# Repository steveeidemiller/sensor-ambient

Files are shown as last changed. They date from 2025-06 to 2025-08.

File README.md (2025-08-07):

# Sensor: Ambient
This ESP32-S3 project is designed to monitor ambient temperature, humidity, barometric pressure, air quality, sound and light levels in areas such as attics, basements, garages, etc. It provides a rich data set that can be integrated into various home automation platforms through MQTT. It also offers a detailed web interface showing current sensor status and graphs of historical data. A telemetry endpoint is also available for use with observability platforms such as Prometheus.

## Features
- Code is designed to be used with the Arduino IDE
- BME680 environmental monitoring for temperature, humidity, atmospheric pressure and air quality
- SPH0645 I2S sound sensor for ambient sound level detection. The sensor does not record audio, it measures sound levels over time.
- VEML7700 I2C light sensor for ambient light level detection. The sensor is not a camera, it uses a single pixel to measure light levels over time.
- MQTT integration with TLS, user/pass and client certificate options
- NTP support for accurate system time which is also reported to MQTT for sensor online/offline detection
- HTTP status page with detailed sensor information, environmentals, system uptime tracking and historical charts
- HTTP metrics endpoint for use with telemetry systems such as Prometheus
- TFT display support that shows current data, sensor uptime and network address information
- AC power on/off sensing to detect power outages at the sensor location
- LiPo battery backup support to power the sensor through moderate power outages

## Screenshots

### Web Interface
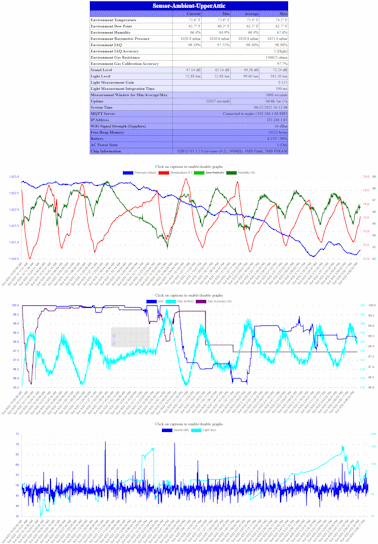
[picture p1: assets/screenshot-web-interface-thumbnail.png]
Web Interface


### MQTT
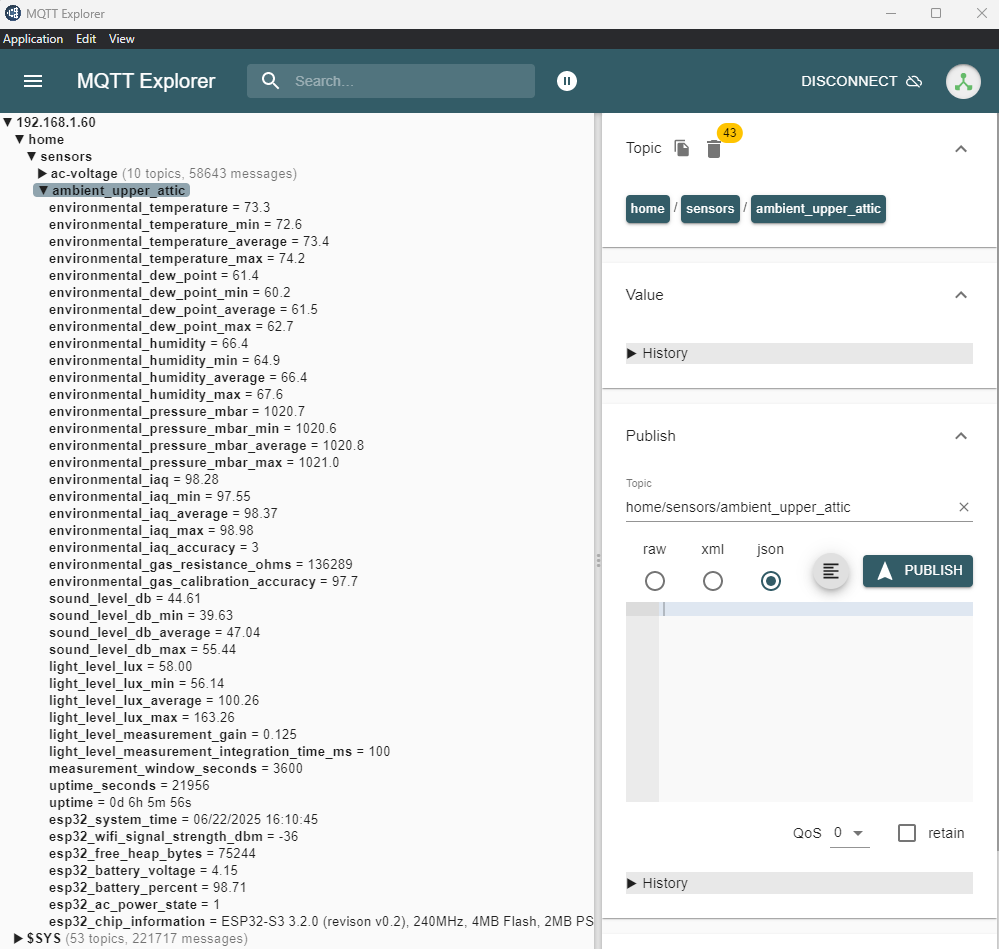
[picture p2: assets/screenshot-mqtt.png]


### Telemetry
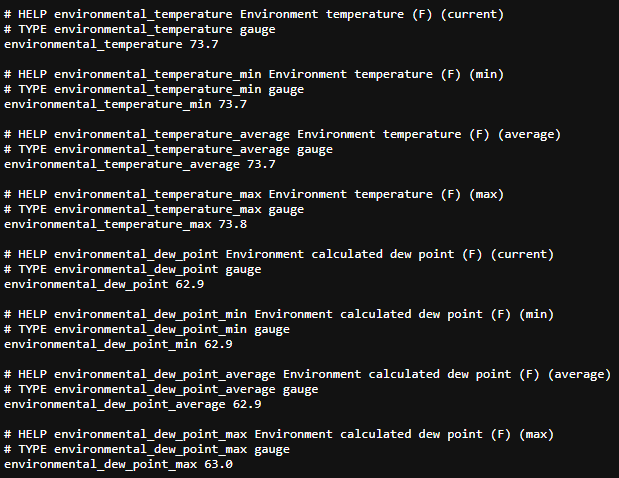
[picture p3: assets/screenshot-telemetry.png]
<br/>
NOTE: This is only a sample of the complete telemetry available.

## Bill of Materials
This solution is based on the ESP32-S3 Reverse TFT Feather from Adafruit. The device integrates a TFT display, a LiPo battery power and charging cicuit, and Qwiic-compatible Stemma QT connectors.
- ESP32-S3 Reverse TFT Feather: [Adafruit #5691](https://www.adafruit.com/product/5691)
- BME680 module for collecting environmental data: [Adafruit #3660](https://www.adafruit.com/product/3660)
- SPH0645LM4H I2S MEMS microphone module: [Adafruit #3421](https://www.adafruit.com/product/3421)
- VEML7700 I2C light sensor module: [Adafruit #4162](https://www.adafruit.com/product/4162)
- Two Stemma QT cables to connect the ESP32 to the VEML7700 and BME280 modules (one 50mm and one 100mm): [Adafruit #4399 and #4210](https://www.adafruit.com/product/4399)
- LiPo battery with JST PH 2.0mm connector (WARNING: Many Amazon batteries do NOT have compatible polarity. Be sure to check the battery connector polarity to ensure that it matches the ESP32 connector!)
- Two 1% precision metal film resistors for AC power sensing: one 22k and one 12k
- Small amount of 24ga solid wire for soldering devices together
- 8 M2x4mm stainless screws for mounting devices to the 3D printed mount
- 8 M3x8mm or M3x10mm stainless screws for fasting the top part of the 3D printed mount to the bottom part

## Implementation Overview
- 3D print the included mount
- Assemble the circuit and mount it on the 3D printed base
- Clone this repository
    ```bash
    git clone https://github.com/steveeidemiller/sensor-ambient.git
    ```
- Copy the `config.example.h` configuration file to `config.h` and edit all values to suit the deployment scenario
- Using the Arduino IDE, upload the main sketch and configuration to the ESP32-S3 Feather: [Flashing instructions may be a little different from other ESP32 devices](https://learn.adafruit.com/esp32-s3-reverse-tft-feather/using-with-arduino-ide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)
- Verify sensor function by using the HTTP status page

# Wiring
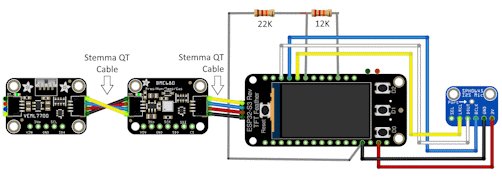
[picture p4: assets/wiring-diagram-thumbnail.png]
Wiring Diagram
<br/>
The BME680 and VEML7700 can be connected with the two Stemma QT cables.

Headers are not needed for this project and if used may actually interfere with the 3D mount. So, there is no need to solder them on to the devices. Instead, simply solder wires directly into the holes. The ESP32 ground pin will need to be shared with one resistor leg and one wire to ground the SPH0645LM4H module. A pair of pliers can be used to slightly flatten the end of the resistor leg so that both wires will fit into the ESP32 hole.

The LiPo battery connector MUST be checked for polarity. Many LiPo batteries do not have the correct polarity for the ESP32 module used in this project. They often have the red and black reversed. The JST connectors are designed to allow removal and reinsertion of the pings, so changing the polarity should be straightforward without damaging the connector. It is recommended to plug the battery in last, once the ESP32 has been programmed.

# Configuration
The project must be properly configured before use. First, copy the `config.example.h` file to a new file named `config.h` and edit all values to suit the deployment scenario per the notes listed here. There are a lot of settings, but default values can be used for many of them.

```cpp
// Network configuration
const char* WIFI_HOSTNAME = "Sensor-Ambient-1"; // Network hostname for the ESP32, such as "Sensor-Upper-Attic", and should be similar to MQTT_TOPIC_BASE below
const char* WIFI_SSID =     "Wifi Network";
const char* WIFI_PASSWORD = "Wifi Password";
```
All three of these values MUST be changed. `WIFI_HOSTNAME` must be a unique host name on your network, and should only use letters, numbers and hyphens. Your wireless network credentials must also be specified. 

```cpp
// NTP for system time
#define NTP_TIMEZONE "CST6CDT,M3.2.0,M11.1.0" // POSIX timezone string which can include daylight savings information if desired. Reference: https://github.com/nayarsystems/posix_tz_db/blob/master/zones.json
#define NTP_SERVER_1 "us.pool.ntp.org"        // NTP pool server within an appropriate region. Reference: https://www.ntppool.org
#define NTP_SERVER_2 "time.nist.gov"          // Alternate NTP pool, or set to NTP_SERVER_1
#define NTP_SERVER_3 "192.168.1.1"            // Alternate NTP pool, or set to NTP_SERVER_1
```
The first value specifies your time zone. Simply select an appropriate value from the provided link. The first two NTP servers can be left as a default for the US. The third NTP server can be your network gateway if it has an NTP service, otherwise any other common NTP server such as `time.cloudflare.com` or `time.google.com` can be used.

```cpp
// TFT display configuration
#define TFT_SCREEN_WIDTH  240
#define TFT_SCREEN_HEIGHT 135
#define TFT_TIMEOUT       30    // After a button press, the display will be powered on for this many seconds before auto-shutoff
#define TFT_ROTATION      2     // 0 = 0, 2 = 180. Reference: https://learn.adafruit.com/adafruit-gfx-graphics-library/rotating-the-display
```
These settings can typically remain at default values. The timeout can be adjusted to suit your preferences. And the rotation can be changed depending on the orientation chosen for mounting the ESP32.

```cpp
// BME680 configuration
#define BME680_ADDRESS 0x77
#define BME680_TEMP_F true        // Set to false for Celsius
#define BME680_TEMP_OFFSET -2.00F // Celsius temperature offset for BME680. Adjust until temperature readings stabilize and match a known reference.
#define BME680_DONCHIAN_ENABLE               true     // Whether Donchian smoothing is enabled for IAQ
#define BME680_DONCHIAN_WINDOW               800      // Donchian smoothing period in number of I2C_INTERVAL polling cycles (default is 6 seconds X this value = smoothing period in seconds)
#define BME680_DONCHIAN_TEMP_RANGE_LIMIT     2.5F     // Donchian range limit for temperature (only used in IAQ calculation)
#define BME680_DONCHIAN_HUMIDITY_RANGE_LIMIT 3.5F     // Donchian range limit for humidity (only used in IAQ calculation)
#define BME680_DONCHIAN_GAS_RANGE_LIMIT      12500.0F // Donchian range limit for gas resistance (only used in IAQ calculation)
```
This block configures the BME680. `0x77` is the default I2C address for the Adafruit module. Fahrenheit is the default temperature scale for this project and can be changed to Celsius with `BME680_TEMP_F false`. Temperature offset will need to be adjusted experimentally, but `-2.00F` degrees Celsius is a good starting point. Donchian smoothing is explained in (the SE_BME680 library)[https://github.com/steveeidemiller/SE_BME680?tab=readme-ov-file#donchian-smoothing-optional], and the default values shown here can typically be used without modification for typical residential scenarios.

```cpp
// SPH0645 I2S sound sensor configuration
#define I2S_PORT_NUM        I2S_NUM_0         // Use I2S port number 0
#define I2S_LRCK_PIN        9                 // Left/Right Clock (Word Select)
#define I2S_BCLK_PIN        6                 // Bit Clock
#define I2S_DATA_IN_PIN     5                 // Data In (DOUT from SPH0645)
#define I2S_MCLK_PIN        I2S_PIN_NO_CHANGE // MCLK pin is not used for SPH0645
#define I2S_DMA_BUF_COUNT   8                 // Number of DMA buffers
#define I2S_DMA_BUF_LEN     256               // Size of each DMA buffer in samples
#define I2S_SAMPLE_RATE     16000             // Audio sample rate (Hz)
#define I2S_BITS_PER_SAMPLE I2S_BITS_PER_SAMPLE_32BIT // SPH0645 outputs data in 32-bit frames (even if only 18-24 bits are valid)
#define I2S_NUM_CHANNELS    I2S_CHANNEL_FMT_ONLY_LEFT // SPH0645 is mono, usually on the left channel
#define SPL_FACTOR          17.5 // Factor to convert the range of the samples to dB SPL (Sound Pressure Level) using the formula: SPL = FACTOR * log10(max - min), where max and min are the maximum and minimum sample values, respectively
```
All of these values can be left at defaults. The `SPL_FACTOR` may need tweaking if the reported sound levels aren't between approximately 35dB and 115dB. Buffer length and sampling rate will mostly affect the frequency bandwidth and responsiveness, but only to a minor degree.

```cpp
// AC power sensing pin
#define AC_POWER_PIN 10 // Attached to the center of the 5V/3.3V resister divider such that the pin gets 3.3V when 5V power exists on the USB bus
```
This can be left at the default if you are following the included wiring diagram. If a different input pin is used, then this value must reflect that.

```cpp
// General measurement configuration
#define MEASUREMENT_WINDOW 3600 // Seconds. Measurements will have min/average/max values calculated over this time period.
```
This value affects the time "window" within which min/average/max values are calculated. Increasing this value will consume more memory, so pay close attention to "Free Heap Memory" on the web interface when increasing this value.

```cpp
// Max update delays. Outputs will be refreshed at least this often.
#define UPDATE_INTERVAL_MQTT    60
#define UPDATE_INTERVAL_TFT     1  // Must be an odd number due to the display toggling function
#define UPDATE_INTERVAL_DATA    60 // Number of seconds between data captures to the PSRAM buffer
```
These can all be left at defaults. This project has multiple outputs and this block configures how often some of those are updated. MQTT updates default to 60 seconds, the TFT display is updated every second, and historical charts on the web interface have data points at 60 second intervals.

```cpp
// HTML history charts (PSRAM data storage)
#define DATA_HISTORY_COUNT    2880 // Number of data elements to keep per stream, with one element per UPDATE_INTERVAL_DATA
```
This can be left at its default. It controls the total amount of time "range" for the web charts. Multiply `UPDATE_INTERVAL_DATA` X `DATA_HISTORY_COUNT` to get the total range in seconds. It is suggested that 24-48 hours be used as a starting point. This value is limited only by the available PSRAM on the ESP32.

```cpp
// MQTT configuration
const char* MQTT_SERVER   = "192.168.1.60"; // MQTT server name or IP
const int   MQTT_PORT     = 8883;           // 1883 is the default port for MQTT, 8883 is the default for MQTTS (TLS)
const char* MQTT_USER     = "MQTT user";    // Null if no authentication is required
const char* MQTT_PASSWORD = "MQTT pass";    // Null if no authentication is required
#define     MQTT_TOPIC_BASE "home/sensors/ambient_1/" // Base topic string for all values from this sensor

// Certificate Authority for TLS connections
static const char CERT_CA[] = R"EOF(
-----BEGIN CERTIFICATE-----
Your CA cert
-----END CERTIFICATE-----
)EOF";
```
This block configures MQTT access.

# Software Installation
With the configuration file complete and the circuit built and mounted, the ESP32 can be flashed. Ensure that the ESP32-S3 device support and all dependent libraries for this project are installed within the Arduino IDE, and then follow the (Adafruit instructions to flash the device)[https://learn.adafruit.com/esp32-s3-reverse-tft-feather/using-with-arduino-ide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]. Basically, the first time the device is flashed, it may need to be placed into bootloader mode. To do that, HOLD DOWN the D0 button while you click Reset. After Reset is clicked, then release D0 button. Generally, this is only needed for the first flash, and every subsequent flash from the Arduino IDE should work as normal.

## Library Dependencies
```cpp
#include <Arduino.h>
#include <Wire.h>
#include <WiFi.h>
#include <WiFiClientSecure.h>     // MQTT TLS support
#include <PubSubClient.h>         // MQTT support from knolleary
#include <ESPmDNS.h>              // mDNS support
#include <WebServer.h>            // HTTP web server support
#include <driver/i2s.h>           // I2S support for SPH0645 sound sensor
#include <Adafruit_MAX1704X.h>    // LiPo battery support
#include <Adafruit_VEML7700.h>    // VEML7700 ambient light sensor support
#include <Adafruit_ST7789.h>      // TFT display support
#include <Fonts/FreeSans9pt7b.h>  // TFT display support
#include <SE_BME680.h>            // BME680 support
#include <hal/efuse_hal.h>        // Espressif ESP32 chip information
#include <time.h>                 // NTP and time support
```

# 3D Printed Mount
STL files are provided for a simple project mount. ABS filament printed with standard Voron settings is recommended, although other common filaments and print settings should work just fine. 

NOTE: The provided mount may not work well with the w.FL antenna variant of the ESP32-S3 Reverse TFT Feather

# License
This project is licensed under the [MIT License](LICENSE).

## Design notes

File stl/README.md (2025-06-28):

# 3D Printer Assets
The `.scad` files are parametric designs for a simple mounting bracket consisting of upper and lower sections. They're built using [OpenSCAD](https://openscad.org/). The open architecture of the mount maximizes exposure for each sensor module.

The ESP32 and each of the sensor modules mount to the round posts on the upper part using M2x4 or M2x5 screws. While four posts are provided for each board, two screws placed diagonally on each should be sufficient. The upper part fastens to the lower part using M3x8 or M3x10 screws. The LiPo battery should be safely contained between the two parts. It can be optionally secured to the back of the upper part using double-sided tape such as 3M VHB tape.

The lower part can be mounted using various methods. It has conical holes for #8 flat-head wood screws. It is recommended that the screw heads are sufficiently recessed to avoid damage to the battery. There is also a single hole along the top of the part that can be used to hang it off of a small nail, 3M Command Hook, etc. Lastly, double-sided tape could also be used.

STL files are provided for each of the two parts. While the design file for the upper part allows for customizable embossed text, the STL file provided here has no text.

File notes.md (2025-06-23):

## Personal Notes About the Sensor Modules and Project Development
I thought I'd share some of my journey while developing this sensor platform.

### BME680
The main sensor for this platform. I started with a BME280 but became strongly attracted to adding air quality sensing to the project, which prompted the upgrade (scope creep?). Accuracy appears comparable between the two, but the BME680 seems a bit more stable and only rarely needs software resets. Bosch provides a closed-source library known as BSEC2 to get the air quality readings along with a couple of other derived calculations. BSEC2 generally works well, but is incredibly sensitive to various timings. As such, it did not work well in this project. I'm pushing the ESP32 pretty hard with all of these sensors, MQTT, WiFi and the web interface. That's a lot of processing and doesn't leave much overhead for BSEC2. It would frequently just miss a reading and then never come back. I tried using a dedicated background thread and adjusting its priority, but nothing seemed to work. Since BSEC2 is closed-source, it's all guesswork as to what was actually failing. This prompted me to create my own library [SE_BME680](https://github.com/steveeidemiller/SE_BME680) and use that. Building that library was a HUGE distraction and a major time sink away from this project. My custom library is no BSEC2, but it's open source, can be adjusted as needed, and offers a respectable IAQ approximation for the win. The gas sensor in the BME680 is hypersensitive to humidity which made a stable IAQ calculation difficult to achieve. In the end, I think my library works reasonably well. I also moved the dew point calculation and temperature offset into SE_BME680 where those things belong. Both projects ended up heavily intertwined.

### VEML7700
I love this sensor. It was by far the easiest to integrate and has been rock solid stable. Rock. Solid. The Adafruit library is awesome, stable, and provides an auto-gain feature to dynamically adjust to current light levels. Cost is super reasonable as well and the module supports Stemma QT cables for easy connections. During testing, it was glorious to see sunrise and sunset show up on the web interface graphs manifested in gentle, sweeping sensor curves. Given the minimal integration hassle and desire to have as much sensing capability packed into this platform as possible, I couldn't NOT include it. The only issues I had were when BSEC2 was running on a different thread without a semaphore and causing I2C bus contention. Public Service Announcement: don't do that. After moving to my own BME680 library, I put all the I2C code on a single thread so I didn't need a semaphore, and everything has been flawless ever since.

### SPH0645
All that's left is sensing sound, right? I actually started with this sensor because I thought the I2S implementation would be a moderate hassle. However, it was pleasantly straightforward. Not easy, but not nearly as bad as the BME680 rabbit hole, not by a long shot. I began by characterizing the sensor to see how it responded to various sound levels and conditions. I noticed that the digitization had a very definite ceiling along with a "soft" floor. It was easy to peg the sensor with the home theater cranked to eleven. The waveforms would range between min and max values reported through the I2S buffers. I expected more of a "full" range on both upper and lower values, representing peak and valley portions of the digitized audio waveform. The upper range hit a definite ceiling and clipped, which was expected. The lower range danced around a value quite a bit higher than zero, but would actually jump all the way down to zero when clipping. It was strange but consistent. Moderate sound levels stayed within a very reasonable and consistent digital range. I struggled with mapping the sensor's detection to a known SPL reference. Eventually I noticed that the dynamic range could be scaled to a standard SPL scale. It was logarithmic, of course, and needed a scaling factor, but it worked flawlessly. Very high audio levels came in around 120dB and the sensor hovered around 40dB or less overnight with a quiet room. This behavior was consistent in different environments over a period of months, so I baked it into the code. The only unresolved issue is with how "noisy" the SPL graph looks on the web interface compared to the other data graphs. More research is needed there. Overall, the sensor has performed extremely well and has given me zero issues on the ESP32. Its cost is also very reasonable, making inclusion into this platform an easy decision.

### Web
I spent a tremendous amount of time on the web interface. Things started with just the text grid (see screenshots above). However, at some point, I wondered if I could push things just a bit further and render graphs for each data stream (scope creep?). Doing so would require lots of memory to store enough historical data points to make a useful graph, and the ESP32 just doesn't have it. This is where the ESP-S3 variants shine, in particular the Reverse TFT Feather chosen for this project. I chose that device for its built-in screen and LiPo support, but it has extended memory as well in the form of PSRAM!! Every now and then I get a stroke of luck like this. It's rare, but it happens once every few decades whether I'm ready or not. Anyway, it was easy to provision the PSRAM, write data into it, and ship that data out over WiFi as a web asset. Ends up being a little over half a MB in my test project. That allowed me to create much larger charts than I originally planned. Big, audacious, colorful graphs in stunning HTML5 glory. It wasn't long before I realized that the graphs were MUCH more important to the web interface than the text grid. In fact, it's not an overstatement to say that the graphs are now a main "selling" feature of this project; they're that awesome. The graphs also became pivotal in the development process by helping identify data and timing issues, particularly when building the massive distraction known as SE_BME680. Ultimately, I think the web interface really became something incredibly useful and visually compelling. You can even set the polling and retention timings to generate week-long graphs!!

### Telemetry
As an unofficial observability enthusiast, it was important to have a Prometheus endpoint in this project. Sure, MQTT is cool, but I wanted the ability to maintain a data repository over time, and the Prometheus/Grafana ecosystem is perfect for that. There are methods to harvest and store data from MQTT as well, but supporting Prometheus/Grafana is the undisputed industry standard. So, we have three outputs: web, MQTT and Prometheus. That's fairly powerful for an ESP32 sensor project, particularly with all of the data this platform can collect.

### 3D Printed Mount
As an armchair engineer coding in front of the TV, I'm perfectly comfortable having electronic modules dangling from cables and precariously spanning a few small breadboards, all of which hang off my laptop's USB port. Things are as they should be. However, that's not something I can mount in the attic (my intended use case). So, I whipped up a simple mount in OpenSCAD. Nothing fancy, certainly not worthy of any design awards, but it gets the job done. The design emphasizes clear access to the sensor media so that the surrounding environment can be accurately measured. It also has a nice cage for the battery with plenty of airflow. And the base has multiple mounting options. If I have time, I'll make a snap-on cover too.

I printed mine on a heavily modified Prusa MK4 (any proper engineer does not run a stock MK4). Black Polymaker ABS was my filament of choice because it was already loaded, with print settings matching the Voron specs because that's what I already had in the slicer at the time. The ABS worked extremely well and the mount is quite heavy duty, perhaps overly so. I'm sure PLA, PETG and other filaments would work nicely, and print settings are likely not that important. 

### Coming Attractions
* Ability to sense the presence of water. Useful when deployed to areas such as basements. I'm currently researching water sensor modules. This will likely be just a yes/no binary detection and won't be reporting water levels, flow rates, etc.
* Ability to capture digital triggers at the deployed location. For example, is some other piece of equipment turned on? Or turned off? That could be detected as "trigger_1" and reported to MQTT, for example. Probably no more than a couple of these.
* Ability to publish a digital "switch" to the deployed location. For example, does the automation platform need to turn on a fan near the sensor, or open a vent? It could simply write "1" to the topic "switch_1", or similar. Again, probably only a couple of these.
* System logging. During development, it would have been nice to have debug output messages and other logged data captured, stored and aggregated in a central location for ease of analysis (like Logstash/ElasticSearch). For production, it would be nice to see why the platform reboots, or when it has trouble connecting to things, etc. Rate limiting will probably be the largest hurdle.
* Maybe some better signal processing on that audio sensor. No guarantees.

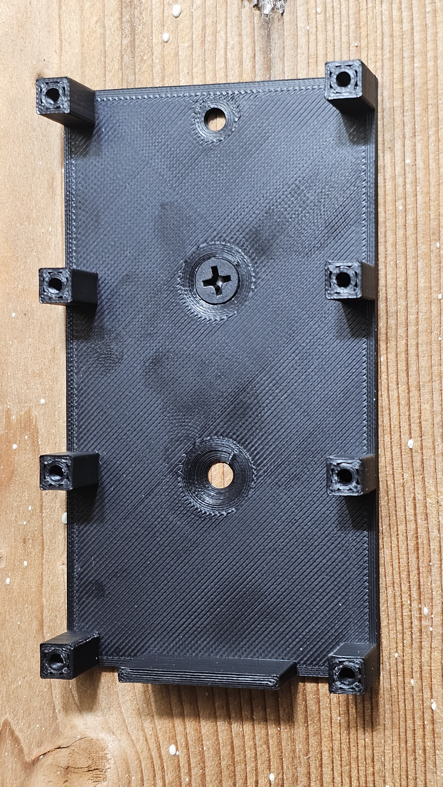
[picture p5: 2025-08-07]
assets/mounting-bracket.jpg

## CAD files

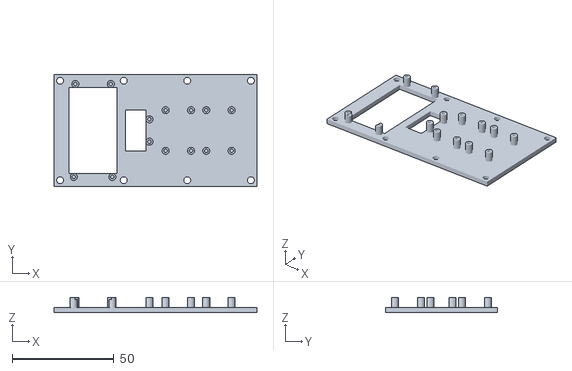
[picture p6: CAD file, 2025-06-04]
stl/AmbientSensor-Upper.stl
100.0 x 55.0 x 7.50

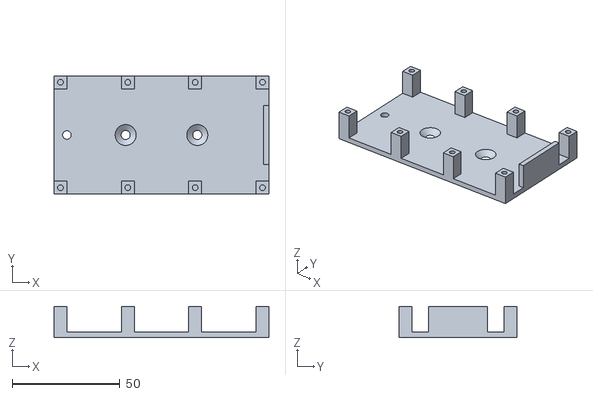
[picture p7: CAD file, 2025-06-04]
stl/AmbientSensor-Lower.stl
100.0 x 55.0 x 14.5

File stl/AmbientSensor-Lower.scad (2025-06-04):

/* CONFIGURATION */

// Threadded screw hole. Suggested values: M2=1.8, M2.5=2.25, M3=2.7, M4=3.6, M5=4.5
postInnerDiameter = 2.7; // 0.01
// Height of the mounting "post", allowing for airflow, bottom mounted devices, etc.
postHeight = 12;
// Thickness of the base plate
baseHeight = 2.5; // 0.01
// Level of detail for rendering
$fs = .2; // 0.01


//
baseLength = 100;
baseWidth = 55;

// Render a "post" as one solid cube with a hollow cylinder/hole inside of it
module post()
{
    difference()
    {
        cube([postOuterWidth, postOuterWidth, postHeight]);
        translate([screwHoleOffset, screwHoleOffset, postHeight / 2])
        {
            // Hollow it out with a slightly taller cylinder
            cylinder(h = postHeight + 1, r = postInnerDiameter / 2, center = true);
        }
    }
}

// Base with mounting holes
difference()
{
    // Base
    cube([baseLength, baseWidth, baseHeight]);

    // Screw holes
    translate([baseLength / 3, baseWidth / 2, -1])
    {
        cylinder(baseHeight+2, r1=3/2, r2=12/2, true);
    }
    translate([baseLength * 2/3, baseWidth / 2, -1])
    {
        cylinder(baseHeight+2, r1=3/2, r2=12/2, true);
    }

    // Hanger hole
    translate([6, baseWidth / 2, -1])
    {
        cylinder(baseHeight + 2, r=2);
    }
}

// Render all posts
screwHoleOffset = 3;
screwCount = 4;
postOuterWidth = screwHoleOffset * 2;
screwInterval = (baseLength - screwHoleOffset * 2) / (screwCount - 1);
for (i = [0 : 1 : screwCount-1]) // [start: inc: end]
{
    translate([i * screwInterval, 0, baseHeight])
    {
        post();
    }
    translate([i * screwInterval, baseWidth - postOuterWidth, baseHeight])
    {
        post();
    }
}

// Battery retainer. NOTE: baseHeight is being used for the thickness of the retainer.
translate([baseLength - baseHeight, baseWidth / 4, baseHeight])
{
    cube([baseHeight, baseWidth / 2, postHeight]);
}

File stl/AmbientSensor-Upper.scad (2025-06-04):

/* CONFIGURATION */

// Threadded screw hole. Suggested values: M2=1.8, M2.5=2.25, M3=2.7, M4=3.6, M5=4.5
postInnerDiameter = 1.8; // 0.01
// Thickness of the post. Suggested values: M2=3.5, M2.5=4.5, M3=5, M4=7, M5=9
postOuterDiameter = 3.5; // 0.01
// Height of the mounting "post", allowing for airflow, bottom mounted devices, etc.
postHeight = 5;
// Thickness of the base plate
baseHeight = 2.5; // 0.01
// Text
baseCaption = "Ambient-1";
// Text size
baseCaptionSize = 6;
// Level of detail for rendering
$fs = .2; // 0.01


//
baseLength = 100;
baseWidth = 55;




/* PROGRAM */

// Calculated dimensions
postInnerRadius = postInnerDiameter / 2;
postOuterRadius = postOuterDiameter / 2;

// Screw hole
module screwHole(x, y)
{
    screwHoleDiameter = 3;
    translate([x, y, baseHeight / 2])
    {
        cylinder(h = baseHeight + 1, r = screwHoleDiameter / 2 + 0.2, center = true);
    }
}

// Render a "post" as one solid cylinder with a hollow cylinder/hole inside of it
module post()
{
    difference()
    {
        cylinder(postHeight, postOuterRadius, postOuterRadius); // Solid
        cylinder(postHeight+1, postInnerRadius, postInnerRadius); // Hollow it out with a slightly taller cylinder
    }
}

// Render four posts in a rectangular configuration, centered on the platform width
module fourPost(x, length, width)
{
    y = (baseWidth - width) / 2;
    translate([x, y, baseHeight]) { post(); }
    translate([x + length, y, baseHeight]) { post(); }
    translate([x + length, y + width, baseHeight]) { post(); }
    translate([x, y + width, baseHeight]) { post(); }
}

// Device locations
esp32L = 17.5;
esp32W = 45.75;
esp32X = 10.5;
esp32Y = (baseWidth - esp32W) / 2;
micW = 11;
micX = 47; // Post location
micY = (baseWidth - micW) / 2;

// Render the rectangular base with screw holes, space under the ESP32, and embossed text
difference()
{
    // Base
    cube([baseLength, baseWidth, baseHeight]);

    // ESP32 cutout
    translate([esp32X - 3, (baseWidth - esp32W + postOuterDiameter)/2, -1])
    {
        cube([esp32L + 6, esp32W - postOuterDiameter, baseHeight + 2]);
    }

    // SPH0645 cutout
    translate([micX - postOuterDiameter/2 - 10, (baseWidth - 20)/2, -1])
    {
        cube([10, 20, baseHeight + 2]);
    }
 
    // Screw holes around the border used to fasten upper piece to lower piece
    screwHoleOffset = 3;
    screwCount = 4;
    screwInterval = (baseLength - screwHoleOffset * 2) / (screwCount - 1);
    for (i = [0 : 1 : screwCount-1]) // [start: inc: end]
    {
        screwHole(screwHoleOffset + i * screwInterval, screwHoleOffset);
        screwHole(screwHoleOffset + i * screwInterval, baseWidth - screwHoleOffset);
    }

    // Recessed text
    translate([baseLength-7, baseWidth/2, baseHeight-.4])
    {
        rotate([0, 0, 90])
        {
            linear_extrude(height = 0.4+1)
            {
                text(text = baseCaption, font = "Arial", size = baseCaptionSize, valign = "center", halign="center");
            }
        }
    }
}

// ESP32 posts
difference()
{
    union()
    {
        // Both left posts act as one for the difference() function
        translate([esp32X - 1.5/2, esp32Y, baseHeight]) { post(); } // Upper left
        translate([esp32X + 1.5/2 + esp32L, esp32Y, baseHeight]) { post(); } // Lower left
    }
    translate([esp32X + 0.5 - 1.5/2, 0, baseHeight + postHeight - 1])
    {
        // Cutout in left posts for WiFi board
        cube([esp32L - 1 + 1.5, baseWidth / 2, 5]);
    }
}
translate([esp32X + esp32L, esp32Y + esp32W, baseHeight]) { post(); } // Lower right
translate([esp32X, esp32Y + esp32W, baseHeight]) { post(); } // Upper right

// SPH0645 microphone posts
translate([micX, micY, baseHeight])
{
    post();
    translate([0, micW, 0]) { post(); }
}

// BME680 and VEML7700 posts
fourPost(55, 12.5, 20.0);
fourPost(75, 12.5, 20.0);

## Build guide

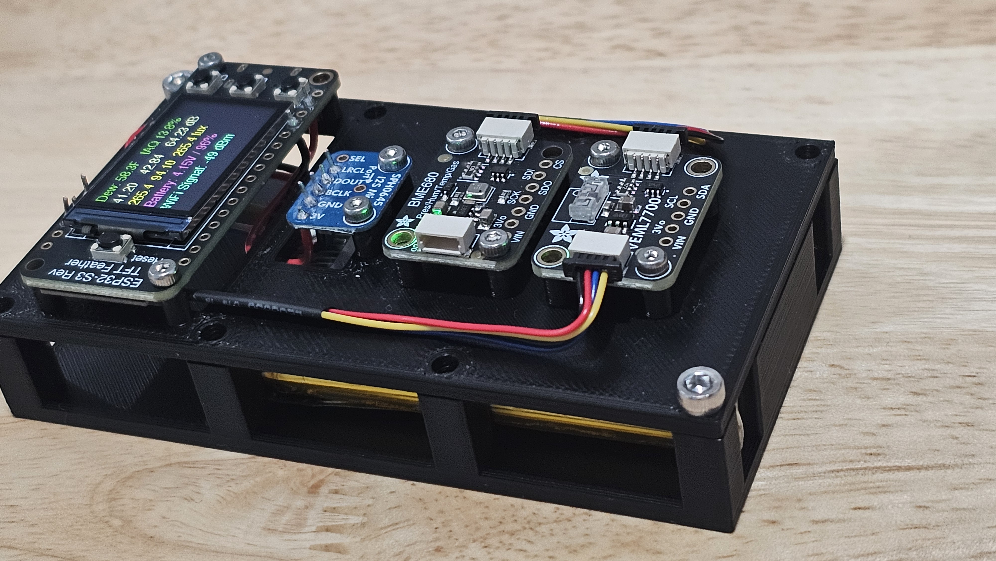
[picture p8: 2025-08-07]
assets/assembly-angle.jpg

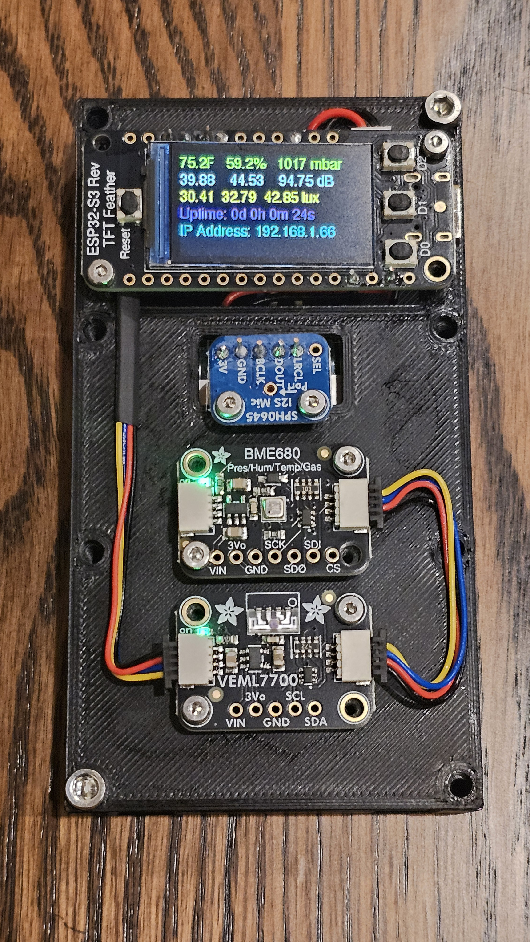
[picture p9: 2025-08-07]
assets/assembly-front.jpg

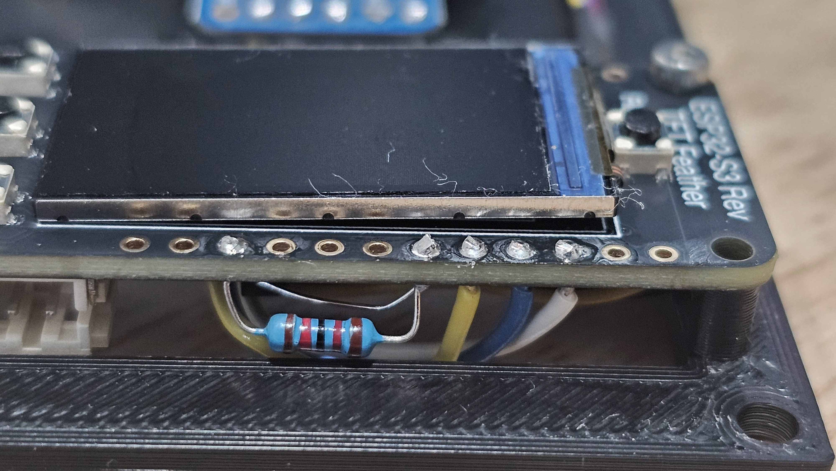
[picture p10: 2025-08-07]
assets/soldering-3.jpg

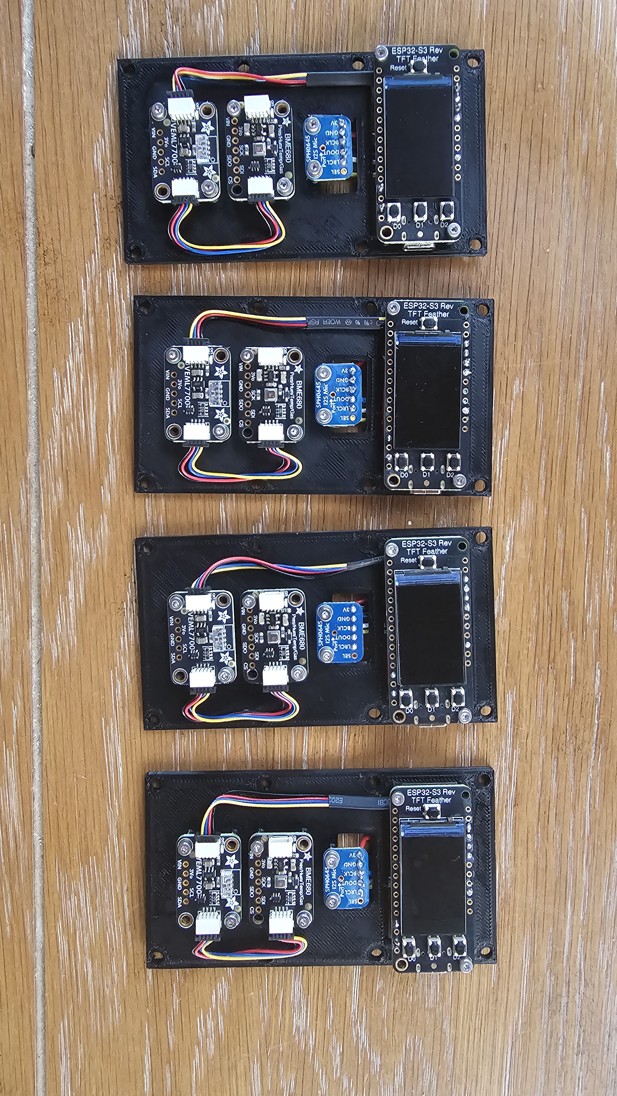
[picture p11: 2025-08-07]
assets/assembly-set.jpg

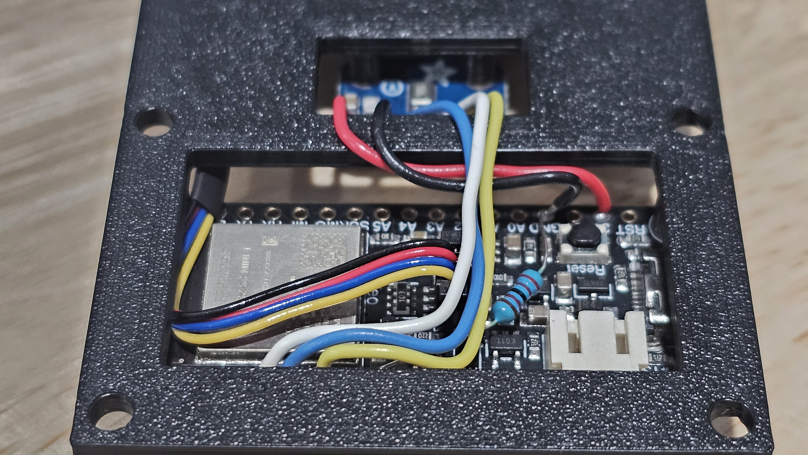
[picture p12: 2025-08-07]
assets/soldering-1.jpg

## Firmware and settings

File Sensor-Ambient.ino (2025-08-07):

/**
 * @file  Sensor-Ambient.ino
 * @brief ESP32-based sound, light and environmental sensor with MQTT, TFT display, and web server support
 */

// Libraries
#include <Arduino.h>
#include <Wire.h>
#include <WiFi.h>
#include <WiFiClientSecure.h>     // MQTT TLS support
#include <PubSubClient.h>         // MQTT support from knolleary
#include <ESPmDNS.h>              // mDNS support
#include <WebServer.h>            // HTTP web server support
#include <driver/i2s.h>           // I2S support for SPH0645 sound sensor
#include <Adafruit_MAX1704X.h>    // LiPo battery support
#include <Adafruit_VEML7700.h>    // VEML7700 ambient light sensor support
#include <Adafruit_ST7789.h>      // TFT display support
#include <Fonts/FreeSans9pt7b.h>  // TFT display support
//#include <Fonts/FreeSans12pt7b.h> // TFT display support
#include <SE_BME680.h>            // BME680 support
#include <hal/efuse_hal.h>        // Espressif ESP32 chip information
#include <time.h>                 // NTP and time support

// App configuration
#include <MeasurementTracker.h>
#include <html.h>                 // HTML templates
#include <config.h>               // The configuration references objects in the above libraries, so include it after those

// Data tracking
#define I2C_INTERVAL 6000 // Millseconds between reading I2C devices, such as the light sensor, environmental sensor, and battery monitor. This value must accomodate the max time each sensor takes for a reading, such as the VEML7700 which can take over 5 seconds, to avoid impacting the BME680 IAQ calculation.
#define MEASUREMENT_TRACKING_DATA_POINTS MEASUREMENT_WINDOW / (I2C_INTERVAL / 1000) // Number of data points to keep in MeasurementTracker() instances to achieve the desired measurement window

// ESP32
char chipInformation[100];   // Chip information buffer

// Web server
WebServer webServer(80);
char webStringBuffer[18 * 1024];

// MQTT
//WiFiClient espClient;     // For non-TLS connections
WiFiClientSecure espClient; // Use WiFiClientSecure for TLS MQTT connections
PubSubClient mqttClient(espClient);
unsigned long mqttLastConnectionAttempt = 0;

// TFT display
Adafruit_ST7789 display = Adafruit_ST7789(TFT_CS, TFT_DC, TFT_RST);
GFXcanvas16 canvas(TFT_SCREEN_WIDTH, TFT_SCREEN_HEIGHT);
int64_t displayTimer = 0; // Timestamp of the last button press used to turn on the display

// SPH0645 I2S sound sensor
SemaphoreHandle_t xMutexSoundSensor; // Mutex to protect shared variables between tasks
int32_t soundSensorDataBuffer[I2S_DMA_BUF_LEN]; // I2S read buffer
MeasurementTracker soundSensorSpl = MeasurementTracker(MEASUREMENT_TRACKING_DATA_POINTS);

// VML7700 light sensor
Adafruit_VEML7700 lightSensor = Adafruit_VEML7700();
SemaphoreHandle_t xMutexLightSensor; // Mutex to protect shared variables between tasks
MeasurementTracker lightSensorLux = MeasurementTracker(MEASUREMENT_TRACKING_DATA_POINTS);
float lightSensorGain = VEML7700_GAIN_1; // Current gain setting for the light sensor, read/updated from the AGC
int lightSensorIntegrationTime = VEML7700_IT_100MS; // Current integration time setting for the light sensor, read/updated from the AGC

// BME680
SE_BME680 bme680;
SemaphoreHandle_t xMutexEnvironmental;     // Mutex to protect shared variables between tasks
bool environmentSensorOK = false;          // True if the sensor is operational
MeasurementTracker environmentTemperature = MeasurementTracker(MEASUREMENT_TRACKING_DATA_POINTS);
MeasurementTracker environmentDewPoint    = MeasurementTracker(MEASUREMENT_TRACKING_DATA_POINTS);
MeasurementTracker environmentHumidity    = MeasurementTracker(MEASUREMENT_TRACKING_DATA_POINTS);
MeasurementTracker environmentPressure    = MeasurementTracker(MEASUREMENT_TRACKING_DATA_POINTS);
MeasurementTracker environmentIAQ         = MeasurementTracker(MEASUREMENT_TRACKING_DATA_POINTS); // 0-100% representing "bad" to "good"
int      environmentIAQAccuracy;           // 0 = unreliable, 1 = low, 2 = medium, 3 = high, 4 = very high
uint32_t environmentGasResistance;         // MOX gas resistance
float    environmentGasAccuracy;           // Accuracy of gas calibration as a percentage
int      environmentGasCalibrationStage;

// Uptime calculations
SemaphoreHandle_t xMutexUptime; // Mutex to protect shared variables between tasks
int64_t uptimeSecondsTotal, uptimeDays, uptimeHours, uptimeMinutes, uptimeSeconds;
int64_t lastUptimeSecondsTotal = 0;
char uptimeStringBuffer[24]; // Used by multiple threads

// LiPo battery and AC power state
SemaphoreHandle_t xMutexBattery; // Mutex to protect shared variables between tasks
Adafruit_MAX17048 max17048;
float batteryVoltage;
float batteryPercent;
int acPowerState; // Is set to 1 when 5V is present on the USB bus (AC power is on), and 0 when not (AC power is off)

// PSRAM historical data streams for the web page charts
#define DATA_ELEMENT_SIZE   10    // Size of one data value as numeric text, with comma delimiter
#define DATA_STREAM_COUNT   10    // There are ten data streams: sound, light, temperature, humidity, dew point, pressure, IAQ, gas resistance, gas accuracy, time
#define DATA_STREAM_SIZE    DATA_HISTORY_COUNT * DATA_ELEMENT_SIZE // Size of a single data stream in bytes
#define DATA_SET_SIZE       DATA_STREAM_SIZE * DATA_STREAM_COUNT   // Size of the entire data set in bytes
unsigned char* psramDataSet;

// Main loop
uint64_t timer = 0; // Copy of the main uptime timer that doesn't need a semaphore
uint64_t lastUpdateTimeMqtt = 0; // Time of last MQTT update
uint64_t lastUpdateTimeTft  = 0; // Time of last OLED update
uint64_t lastUpdateTimeData = 0; // Time of last data set update

// Helper function to return the current "clock", which is seconds of uptime
inline int64_t systemSeconds()
{
  return esp_timer_get_time() / 1000000;
}

///////////////////////////////////////////////////////////////////////////////////////////////////////////////////////
// Networking
///////////////////////////////////////////////////////////////////////////////////////////////////////////////////////

// WiFi setup
void setupWiFi()
{
  // Static IP configuration
  if (WIFI_STATIC_IP && !WiFi.config(WIFI_HOST, WIFI_GATEWAY, WIFI_SUBNET, WIFI_PRIMARY_DNS, WIFI_SECONDARY_DNS))
  {
    Serial.println("WiFi: Failed to configure static IP");
    //TODO: error handling
  }

  // Connect
  WiFi.setHostname(WIFI_HOSTNAME);
  Serial.print("WiFi: Connecting to "); Serial.print(WIFI_SSID); Serial.print(" ..");
  WiFi.begin(WIFI_SSID, WIFI_PASSWORD);
  while (WiFi.status() != WL_CONNECTED)
  {
    Serial.print('.');
    delay(250);
  }
  Serial.println();
  Serial.print("WiFi: IP address "); Serial.println(WiFi.localIP());
}

// Multicast DNS setup so that "hostname.local" works on the network
void setupMDNS()
{
  if (!MDNS.begin(WIFI_HOSTNAME))
  {
    Serial.println("mDNS: Error setting up responder");
  }
  else
  {
    Serial.print("mDNS: Responder started for host name "); Serial.print(WIFI_HOSTNAME); Serial.println(".local");
    MDNS.addService("https", "tcp", 443); //Advertise services
    //MDNS.addServiceText("http", "tcp", "Service", "Web"); //Advertise service properties
    //MDNS.addServiceText("http", "tcp", "Device", "ESP32"); //Advertise service properties
  }
}

///////////////////////////////////////////////////////////////////////////////////////////////////////////////////////
// Web Server
///////////////////////////////////////////////////////////////////////////////////////////////////////////////////////

// Web helper function for using sprintf() to append to the web string buffer
inline int bytesAdded(int sprintfReturnValue)
{
  // Ignore negative/error sprintf() return values so they don't affect pointer arithmetic in the calling function
  return sprintfReturnValue > 0 ? sprintfReturnValue : 0;
}

// Web helper function to append a string to the web string buffer
inline int buffercat(char* dest, const char* source)
{
  strcpy(dest, source);
  return strlen(source);
}

// Web helper function to describe IAQ accuracy values
char* webFormatIAQAccuracy(int a)
{
  switch (a)
  {
    case 1: return "Low";
    case 2: return "Medium";
    case 3: return "High";
    case 4: return "Very high";
  }
  return "Unreliable";
}

// Web helper function to output current/min/average/max values from a MeasurementTracker instance
char* webRenderMeasurementValues(char* buffer, char* description, char* format, MeasurementTracker& measurement)
{
  buffer += buffercat(buffer, description); // Start of table row
  buffer += bytesAdded(sprintf(buffer, format, measurement.min));
  buffer += bytesAdded(sprintf(buffer, format, measurement.max));
  buffer += bytesAdded(sprintf(buffer, format, measurement.average));
  buffer += bytesAdded(sprintf(buffer, format, measurement.current));
  buffer += buffercat(buffer, "</tr>"); // Close the table row 
  return buffer;
}

// Web helper function to render the main data table (the "dashboard") at the specified buffer position
char* webRenderDashboard(char* buffer)
{
  IPAddress ip = WiFi.localIP();
  struct tm timeInfo; // NTP

  buffer += buffercat(buffer, "<table id=\"dashboard\" class=\"sensor\" cellspacing=\"0\" cellpadding=\"3\">"); // Sensor data table
  buffer += bytesAdded(sprintf(buffer, "<tr><th colspan=\"5\" class=\"header\">%s</th></tr>", WIFI_HOSTNAME)); // Network hostname
  buffer += buffercat(buffer, "<tr class=\"subheader\"><th></th><td>Min</td><td>Max</td><td>Average</td><td>Current</td></tr>");

  xSemaphoreTake(xMutexEnvironmental, portMAX_DELAY); // Start accessing the environmental data (calculated on a different thread)
  if (environmentSensorOK)
  {
    #ifdef BME680_TEMP_F
      #define WEB_UNITS "F"
    #else
      #define WEB_UNITS "C"
    #endif
    buffer = webRenderMeasurementValues(buffer, "<tr class=\"environmental\"><th>Environment Temperature</th>",         "<td>%0.1f&deg; " WEB_UNITS "</td>", environmentTemperature);
    buffer = webRenderMeasurementValues(buffer, "<tr class=\"environmental\"><th>Environment Dew Point</th>",           "<td>%0.1f&deg; " WEB_UNITS "</td>", environmentDewPoint);
    buffer = webRenderMeasurementValues(buffer, "<tr class=\"environmental\"><th>Environment Humidity</th>",            "<td>%0.1f%%</td>",                  environmentHumidity);
    buffer = webRenderMeasurementValues(buffer, "<tr class=\"environmental\"><th>Environment Barometric Pressure</th>", "<td>%0.1f mbar</td>",               environmentPressure);
    if (environmentIAQAccuracy)
    {
      buffer = webRenderMeasurementValues(buffer, "<tr class=\"environmental\"><th>Environment IAQ</th>", "<td>%0.2f%%</td>", environmentIAQ);
    }  
    buffer += bytesAdded(sprintf(buffer, "<tr class=\"environmental\"><th>Environment IAQ Accuracy</th><td colspan=\"4\">%d (%s)</td></tr>",             environmentIAQAccuracy, webFormatIAQAccuracy(environmentIAQAccuracy)));
    buffer += bytesAdded(sprintf(buffer, "<tr class=\"environmental\"><th>Environment Gas Resistance</th><td colspan=\"4\">%d ohms</td></tr>",           environmentGasResistance));
    buffer += bytesAdded(sprintf(buffer, "<tr class=\"environmental\"><th>Environment Gas Calibration Accuracy</th><td colspan=\"4\">%0.1f%%</td></tr>", environmentGasAccuracy));
  }
  else
  {
    buffer += buffercat(buffer, "<tr class=\"environmental\"><th>Environment Sensor Stabilized?</th><td colspan=\"4\">0 (No)</td></tr>");
  }
  xSemaphoreGive(xMutexEnvironmental); // Done with environmental data

  xSemaphoreTake(xMutexSoundSensor, portMAX_DELAY); // Start accessing sound data (measured on a different thread)
  buffer = webRenderMeasurementValues(buffer, "<tr class=\"soundlight\"><th>Sound Level</th>", "<td>%0.2f dB</td>", soundSensorSpl);
  xSemaphoreGive(xMutexSoundSensor); // Done with sound data

  xSemaphoreTake(xMutexLightSensor, portMAX_DELAY); // Start accessing light data (measured on a different thread)
  buffer = webRenderMeasurementValues(buffer, "<tr class=\"soundlight\"><th>Light Level</th>", "<td>%0.2f lux</td>", lightSensorLux);
  buffer += bytesAdded(sprintf(buffer, "<tr class=\"soundlight\"><th>Light Measurement Gain</th><td colspan=\"4\">%0.3f</td></tr>", lightSensorGain));
  buffer += bytesAdded(sprintf(buffer, "<tr class=\"soundlight\"><th>Light Measurement Integration Time</th><td colspan=\"4\">%d ms</td></tr>", lightSensorIntegrationTime));
  xSemaphoreGive(xMutexLightSensor); // Done with light data

  xSemaphoreTake(xMutexUptime, portMAX_DELAY); // Start accessing the uptime data (calculated on a different thread)
  buffer += bytesAdded(sprintf(buffer, "<tr class=\"system\"><th>Measurement Window for Min/Average/Max</th><td colspan=\"4\">%d seconds</td></tr>", MEASUREMENT_WINDOW));
  buffer += bytesAdded(sprintf(buffer, "<tr class=\"system\"><th>Uptime</th><td colspan=\"2\">%lld seconds</td><td colspan=\"2\">%s</td></tr>", uptimeSecondsTotal, uptimeStringBuffer));
  if (getLocalTime(&timeInfo))
  {
    buffer += bytesAdded(sprintf(buffer, "<tr class=\"system\"><th>System Time</th><td colspan=\"4\">%02d/%02d/%02d %02d:%02d:%02d</td></tr>", timeInfo.tm_mon + 1, timeInfo.tm_mday, timeInfo.tm_year + 1900, timeInfo.tm_hour, timeInfo.tm_min, timeInfo.tm_sec));
  }
  xSemaphoreGive(xMutexUptime); // Done with uptime data

  buffer += bytesAdded(sprintf(buffer, "<tr class=\"network\"><th>MQTT Server</th><td colspan=\"4\">%s mqtts://%s:%d</td></tr>", mqttClient.connected() ? "Connected to" : "Disconnected from ", MQTT_SERVER, MQTT_PORT));
  buffer += bytesAdded(sprintf(buffer, "<tr class=\"network\"><th>IP Address</th><td colspan=\"4\">%d.%d.%d.%d</td></tr>", ip[0], ip[1], ip[2], ip[3]));
  buffer += bytesAdded(sprintf(buffer, "<tr class=\"network\"><th>WiFi Signal Strength (%s)</th><td colspan=\"4\">%d dBm</td></tr>", WIFI_SSID, WiFi.RSSI()));

  buffer += bytesAdded(sprintf(buffer, "<tr class=\"chip\"><th>Free Heap Memory</th><td colspan=\"4\">%d bytes</td></tr>", ESP.getFreeHeap())); // ESP32 free heap memory, which indicates if the program still has enough memory to run effectively
  xSemaphoreTake(xMutexBattery, portMAX_DELAY); // Start accessing the battery data (calculated on a different thread)
  buffer += bytesAdded(sprintf(buffer, "<tr class=\"chip\"><th>Battery</th><td colspan=\"4\">%0.2fV / %0.0f%%</td></tr>", batteryVoltage, batteryPercent)); // LiPo battery
  buffer += bytesAdded(sprintf(buffer, "<tr class=\"chip\"><th>AC Power State</th><td colspan=\"4\">%s</td></tr>", acPowerState ? "1 (On)" : "0 (Off)")); // AC power sense
  xSemaphoreGive(xMutexBattery); // Done with battery data
  buffer += bytesAdded(sprintf(buffer, "<tr class=\"chip\"><th>Chip Information</th><td colspan=\"4\">%s</td></tr>", chipInformation));

  buffer += buffercat(buffer, "</table>"); // Sensor data table

  return buffer;
}

// Web server 404 handler
void webHandler404()
{
  webServer.send(404, "text/plain", "Not found");
}

// Web server "/" GET handler (for root/home page)
void webHandlerRoot()
{
  // Build the HTML response in the web string buffer
  char* buffer = webStringBuffer; // "buffer" will be used to walk through the "webStringBuffer" work area using pointer arithmetic
  buffer += bytesAdded(sprintf(buffer, htmlHeader, WIFI_HOSTNAME, systemSeconds(), BME680_TEMP_F ? "F" : "C")); // Hostname gets added to the HTML <title> inside the template header, and the ESP32 current seconds counter and temperature units are used by JavaScript for the charts
  buffer  = webRenderDashboard(buffer);
  buffer += buffercat(buffer, htmlFooter); // HTML template footer

  // Send the HTML response to the client
  webServer.send(200, "text/html", webStringBuffer);
}

// Web server "/dashboard" GET handler (for AJAX updates on the main interface)
void webHandlerDashboard()
{
  webRenderDashboard(webStringBuffer);
  webServer.send(200, "text/plain", webStringBuffer);
}

// Helper functions to append one Prometheus style metric to the web buffer, such as the following where name="light_level_lux", description="Light level (current)", format="0.2f", metric=65.0F:
//    # HELP light_level_lux Light level (current)
//    # TYPE light_level_lux gauge
//    light_level_lux 65.00
char* webAppendMetric(char* buffer, char* name, char* description, char* format, float metric)
{
  buffer += buffercat(buffer, "# HELP "); buffer += buffercat(buffer, name); buffer += buffercat(buffer, " "); buffer += buffercat(buffer, description); buffer += buffercat(buffer, "\n");
  buffer += buffercat(buffer, "# TYPE "); buffer += buffercat(buffer, name); buffer += buffercat(buffer, " gauge\n");
  buffer += buffercat(buffer, name); buffer += buffercat(buffer, " "); buffer += bytesAdded(sprintf(buffer, format, metric)); buffer += buffercat(buffer, "\n\n");
  return buffer;
}
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
void loop()
{
  // Uptime calculations: How long has the ESP32 been running since it was booted up?
  xSemaphoreTake(xMutexUptime, portMAX_DELAY); // Start accessing the uptime data
  bool newSecond = false;
  uptimeSecondsTotal = systemSeconds();
  if (uptimeSecondsTotal > lastUptimeSecondsTotal)
  {
    newSecond = true;
    int64_t seconds = uptimeSecondsTotal;
    uptimeDays = seconds / 86400;
    seconds -= uptimeDays * 86400;
    uptimeHours = seconds / 3600;
    seconds -= uptimeHours * 3600;
    uptimeMinutes = seconds / 60;
    uptimeSeconds = seconds - uptimeMinutes * 60;
    sprintf(uptimeStringBuffer, "%lldd %lldh %lldm %llds", uptimeDays, uptimeHours, uptimeMinutes, uptimeSeconds);
    lastUptimeSecondsTotal = uptimeSecondsTotal;
  }
  timer = uptimeSecondsTotal; // Copy the timer so it can be used without the semaphore
  xSemaphoreGive(xMutexUptime); // Done with uptime data

  // MQTT connection management
  if (!mqttClient.connected()) connectMQTT(); else mqttClient.loop();

  // Web server request management
  webServer.handleClient();

  // Update outputs every specified update interval, and usually the first-time through the loop()
  bool updateTft  = timer - lastUpdateTimeTft >= UPDATE_INTERVAL_TFT;
  if (updateTft || lastUpdateTimeTft == 0)
  {
      // Update the display
      updateDisplay();
      lastUpdateTimeTft = timer;
  }
  bool updateMqtt = timer - lastUpdateTimeMqtt >= UPDATE_INTERVAL_MQTT;
  if (updateMqtt || lastUpdateTimeMqtt == 0)
  {
      // Update MQTT
      updateMQTT();
      lastUpdateTimeMqtt = timer;
  }
  bool updateData = timer - lastUpdateTimeData >= UPDATE_INTERVAL_DATA;
  if (updateData) // Don't want to capture data the first time through the loop() because there likely won't be any useful data
  {
      // Update the data set
      updateDataSet();
      lastUpdateTimeData = timer;
  }

  // Turn on the TFT display backlight for a few seconds when a button is pressed. The display is constantly updated, so buttons just turn the backlight on/off.
  if (digitalRead(0) == 0 || digitalRead(1) || digitalRead(1)) // NOTE: D0 is different
  {
    displayTimer = timer;
    digitalWrite(TFT_BACKLITE, HIGH); // Power on the TFT backlight
  }
  else if (timer - displayTimer == TFT_TIMEOUT)
  {
    digitalWrite(TFT_BACKLITE, LOW); // Power off the TFT backlight
  }

  // Yield to other tasks, and slow down the main loop a little
  delay(5); // Non-blocking delay on ESP32, in milliseconds
}

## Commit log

2025-04-22 Added peak value tracking for light and sound, button press detection. Significant refactoring in rest of code.
2025-04-23 Added logic to display data on the TFT, added AC power state sensing, general refactoring
2025-05-09 Added dew point calculation, refactored internal temperature tracking to be in Celsius and convert to Fahrenheit only on output if specified.
2025-05-20 Fixed TFT rotation, added air quality metrics to TFT display
    [Sensor-Ambient.ino, config.example.h]
2025-06-04 BSEC2 final. Added STL files.
    [AmbientSensor-Lower.scad, AmbientSensor-Lower.stl, AmbientSensor-Upper.scad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]
2025-06-28 Added wiring diagram
    [Fritzing.fzz]
